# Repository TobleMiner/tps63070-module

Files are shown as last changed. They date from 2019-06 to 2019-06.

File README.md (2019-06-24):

2 - 16 V step-up/down module
============================

Simple 2 - 16 V step-up/down DC-DC module, footprint-compatible to MP1584EN

Optional headers for regulator control and power good signals.

# PCB

## Top
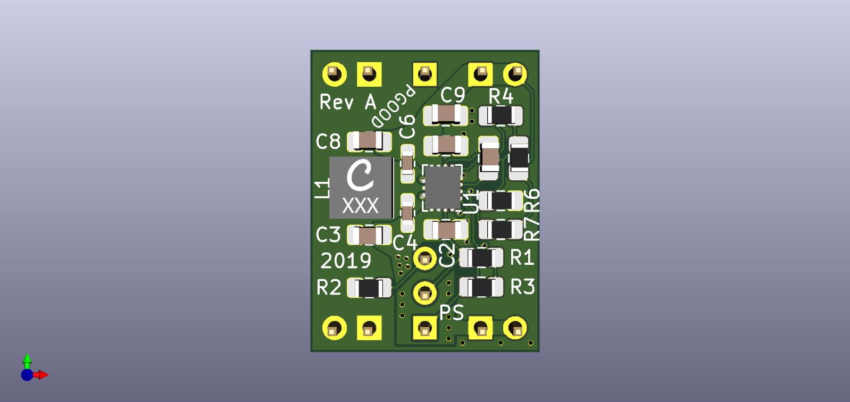
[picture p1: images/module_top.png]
PCB top


## Bottom
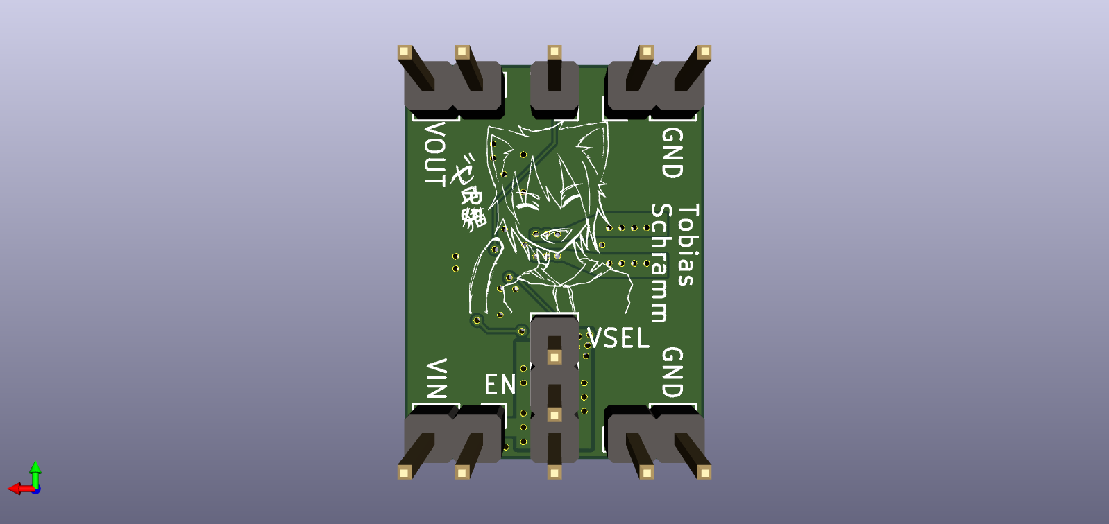
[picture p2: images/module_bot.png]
PCB bottom


# Library

This design comes with reference KiCAD module schematic symbols, footprints
and 3d models. Copy

* models
* tps63070-module.lib
* tps63070-module.pretty

to the root of your project and include the schematic symbols from
`tps63070-module.lib` as well as the footprints from `tps63070-module.pretty`.

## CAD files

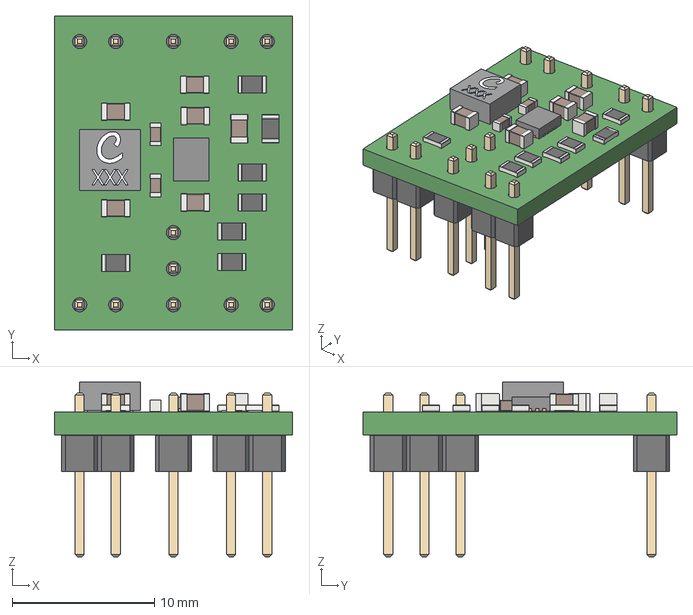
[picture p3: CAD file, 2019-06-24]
models/module-full.step
16.8 x 22.1 x 12.3 mm

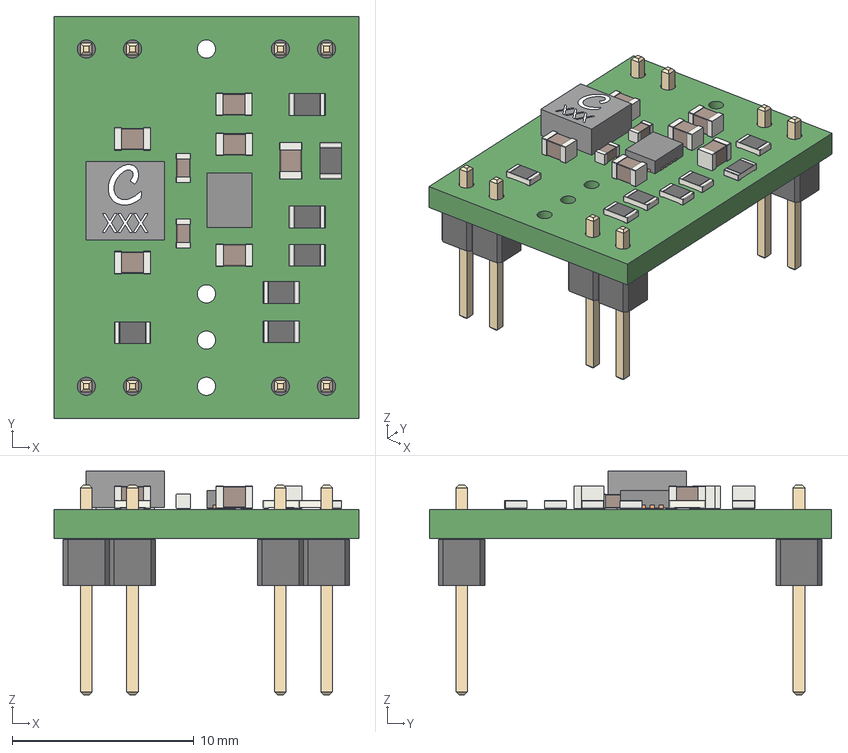
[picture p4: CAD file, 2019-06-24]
models/module-compat.step
16.8 x 22.1 x 12.3 mm

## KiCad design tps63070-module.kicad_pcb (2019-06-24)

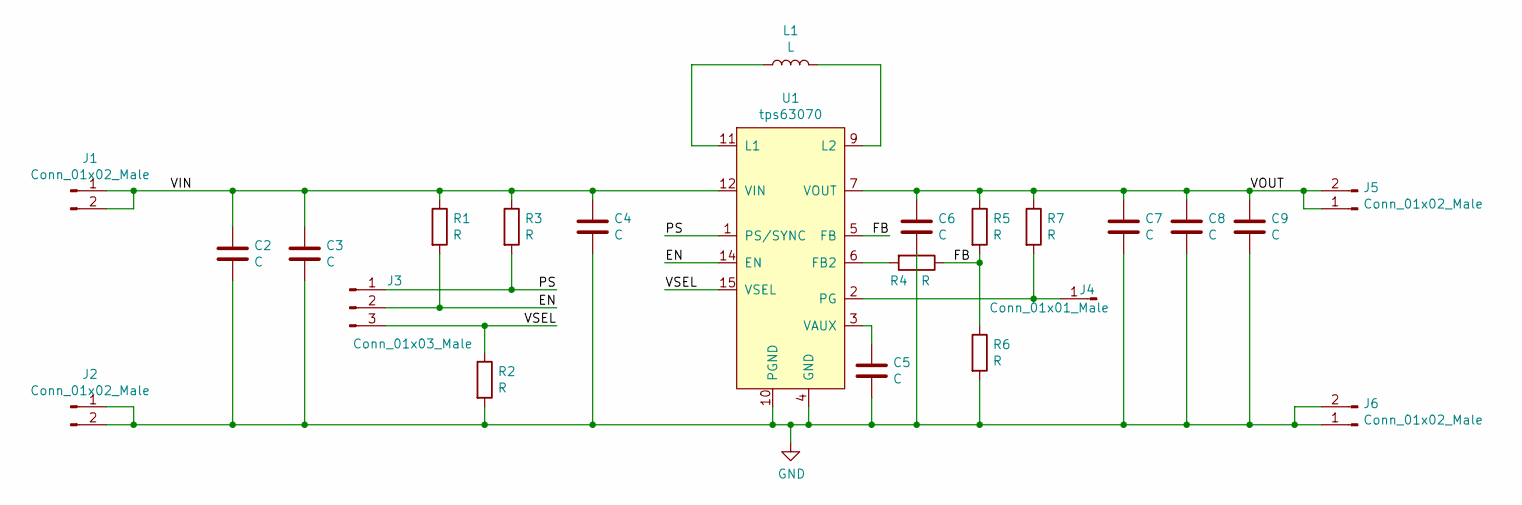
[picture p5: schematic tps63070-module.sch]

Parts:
C2, C3, C5, C7, C8, C9: C; C_0805_2012Metric_Pad1.15x1.40mm_HandSolder
C4, C6: C; C_0603_1608Metric_Pad1.05x0.95mm_HandSolder
J1, J2, J5, J6: Conn_01x02_Male; PinHeader_1x02_P2.54mm_Vertical
J3: Conn_01x03_Male; PinHeader_1x03_P2.54mm_Vertical
J4: Conn_01x01_Male; PinHeader_1x01_P2.54mm_Vertical
L1: L; L_Coilcraft_XxL4020
R1, R2, R3, R4, R5, R6, R7: R; R_0805_2012Metric_Pad1.15x1.40mm_HandSolder
U1: tps63070; VQFN-HR-15

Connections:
/EN: J3.2, R1.2, U1.14 (EN)
/FB: R4.1, R5.2, R6.1, U1.5 (FB)
/PS: J3.1, R3.2, U1.1 (PS/SYNC)
/VIN: C2.1, C3.1, C4.1, J1.1, J1.2, R1.1, R3.1, U1.12 (VIN)
/VOUT: C6.1, C7.1, C8.1, C9.1, J5.1, J5.2, R5.1, R7.1, U1.7 (VOUT)
/VSEL: J3.3, R2.1, U1.15 (VSEL)
GND: C2.2, C3.2, C4.2, C5.1, C6.2, C7.2, C8.2, C9.2, J2.1, J2.2, J6.1, J6.2, R2.2, R6.2, U1.4 (GND), U1.10 (PGND)
unnamed: C5.2, U1.3 (VAUX)
unnamed: J4.1, R7.2, U1.2 (PG)
unnamed: L1.1, U1.11 (L1)
unnamed: L1.2, U1.9 (L2)
unnamed: R4.2, U1.6 (FB2)

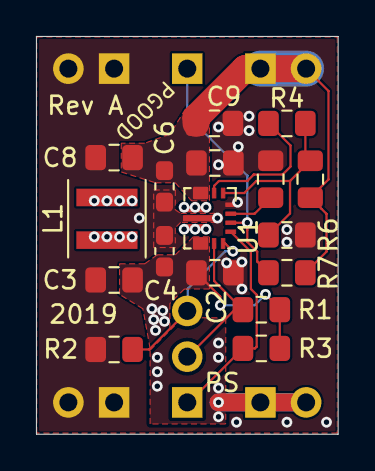
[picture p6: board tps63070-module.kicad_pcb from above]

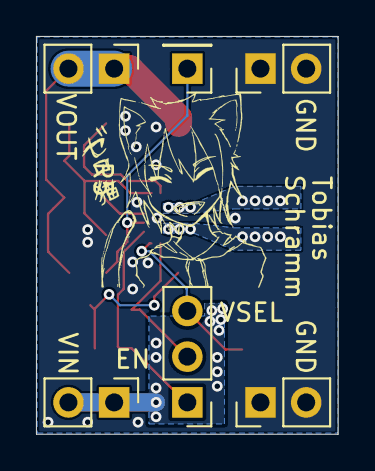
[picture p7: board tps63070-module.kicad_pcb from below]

Board: 2 copper layers, 16.8 x 22.1 mm, 23 parts (6 on the bottom side), 12 nets.

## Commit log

2019-06-16 Add schematic
    [tps63070-module.sch]
2019-06-16 Place components
    [tps63070-module.kicad_pcb]
2019-06-17 Do some routing
    [tps63070-module.kicad_pcb]
2019-06-17 Add groundplanes
    [tps63070-module.kicad_pcb]
2019-06-19 Route board
    [tps63070-module.kicad_pcb]
2019-06-19 Add PCB art
    [tps63070-module.kicad_pcb]
2019-06-19 Connect VOUT on top Cu layer, too
    [tps63070-module.kicad_pcb]
2019-06-19 Add more silkscreen designators
    [tps63070-module.kicad_pcb]
2019-06-24 Add 3d models
    [tps63070-module.kicad_pcb, tps63070-module.sch]
2019-06-24 Add module footprints and 3d models
    [module-compat.step, module-full.step, tps63070-module.kicad_pcb]
2019-06-24 Reposition designator C4
    [tps63070-module.kicad_pcb]
2019-06-24 Add instructions on using KiCad models
2019-06-25 Fix module footprints
    Pins were flipped horizontally
2019-06-25 Optimize PCB footprint
    * Move front exclusion zone to include only pin headers
    * Enlarge front silkscreen outline to cover whole area of module
